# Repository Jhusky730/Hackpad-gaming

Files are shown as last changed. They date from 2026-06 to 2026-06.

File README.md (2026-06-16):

# Hackpad-gaming
This is my hackpad. It consists of a 3x3 key matrix with RGB LEDs, an OLED screen, and a rotary encoder.

Model of hackpad:

54308050-a742-41d1-adb0-8d3222a5e59c

Screenshot of Shematic for PCB:



Screenshot of PCB:



Layers of the keyboard:



Top side of both parts:



The cases act as a clamp and ledge for the pcb to hold it in place:



Bill Of Materials: 
1x Seeed XIAO RP2040  
1x 0.91" OLED9x MX style 1u switches  
9x white blank DSA keycaps  
9x SK6812 Mini-E LEDs  
10x 1N4148 DO-35 Diodes  
1x EC11E Rotary Encoder (With Push Button)  
1x Top case(3D printed)  
1x Middle case(3D printed)  
1x Bottom case(3D printed)  
4x M3x5mx4mm heatset inserts  
4x M3x6mm screws (I will buy these)

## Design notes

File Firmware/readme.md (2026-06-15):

# my_hackpad

my_hackpad

A fully custom 9-key mechanical macropad featuring an orthilinear 3x3 layout, an SSD1306 OLED screen, a rotary encoder, and an addressable per-key SK6812MINI-E RGB matrix. It is pre-configured with a daily desktop utility layer and a dedicated tactical combat deck for EVE Online.

* Keyboard Maintainer: [Jack Huskinson](https://github.com/Jhusky730)
* Hardware Supported: Custom 3x3 PCB, Seeed Studio XIAO RP2040 Controller
* Hardware Availability: Open-source PCB files / Self-sourced components

## Compiling the Firmware

To compile the default layout for this keyboard, run the following command in your QMK CLI environment:

    qmk compile -kb my_hackpad -km default

## Flashing the Microcontroller

Since the Seeed Studio XIAO RP2040 uses a UF2 bootloader, you can flash it using the standard drag-and-drop method:

1. Compile the firmware using the command above to generate the `.uf2` file.
2. Put the keyboard into **Bootloader mode** (see instructions below).
3. A mass storage drive named `RPI-RP2` will appear on your computer.
4. Drag and drop the compiled `my_hackpad_default.uf2` file directly onto that drive. The board will automatically flash and reboot.

See the [build environment setup](https://docs.qmk.fm/#/getting_started_build_tools) and the [make instructions](https://docs.qmk.fm/#/getting_started_make_guide) for more information. Brand new to QMK? Start with our [Complete Newbs Guide](https://docs.qmk.fm/#/newbs).

## Bootloader

Because your board uses a modern RP2040 processor, you can enter the bootloader in 2 reliable hardware ways:

* **Physical Button Combination**: Hold down the **B** (Boot) button on the underside of the XIAO RP2040 module, press and release the **R** (Reset) button, and then release the Boot button.
* **Physical Pads**: If your custom PCB exposes them, briefly short the two `RST` pads together while the device is plugged in.

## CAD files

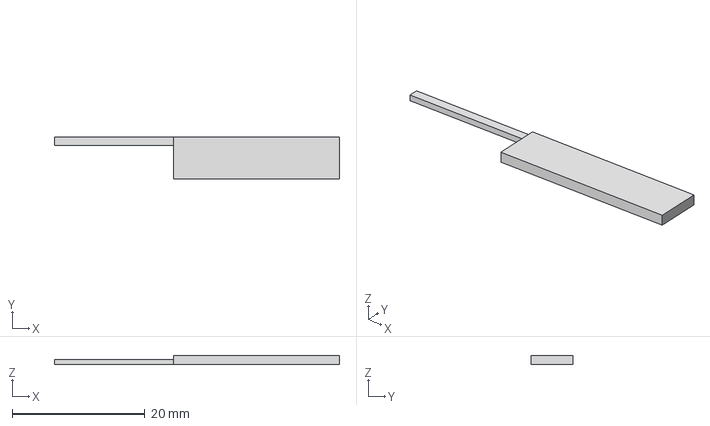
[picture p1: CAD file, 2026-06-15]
Production/Middle.step
43.0 x 6.30 x 1.40 mm

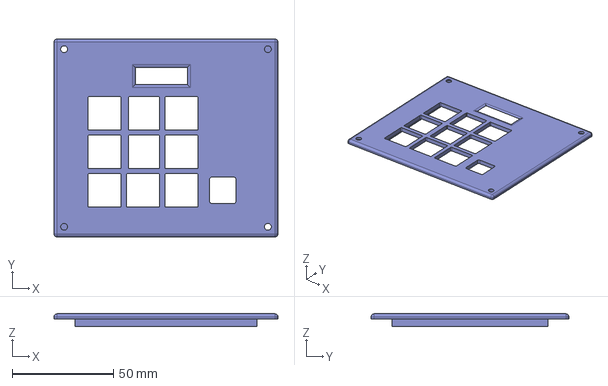
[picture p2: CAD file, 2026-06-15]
Production/Top.step
110.8 x 97.8 x 6.20 mm

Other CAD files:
Production/Bottom.step

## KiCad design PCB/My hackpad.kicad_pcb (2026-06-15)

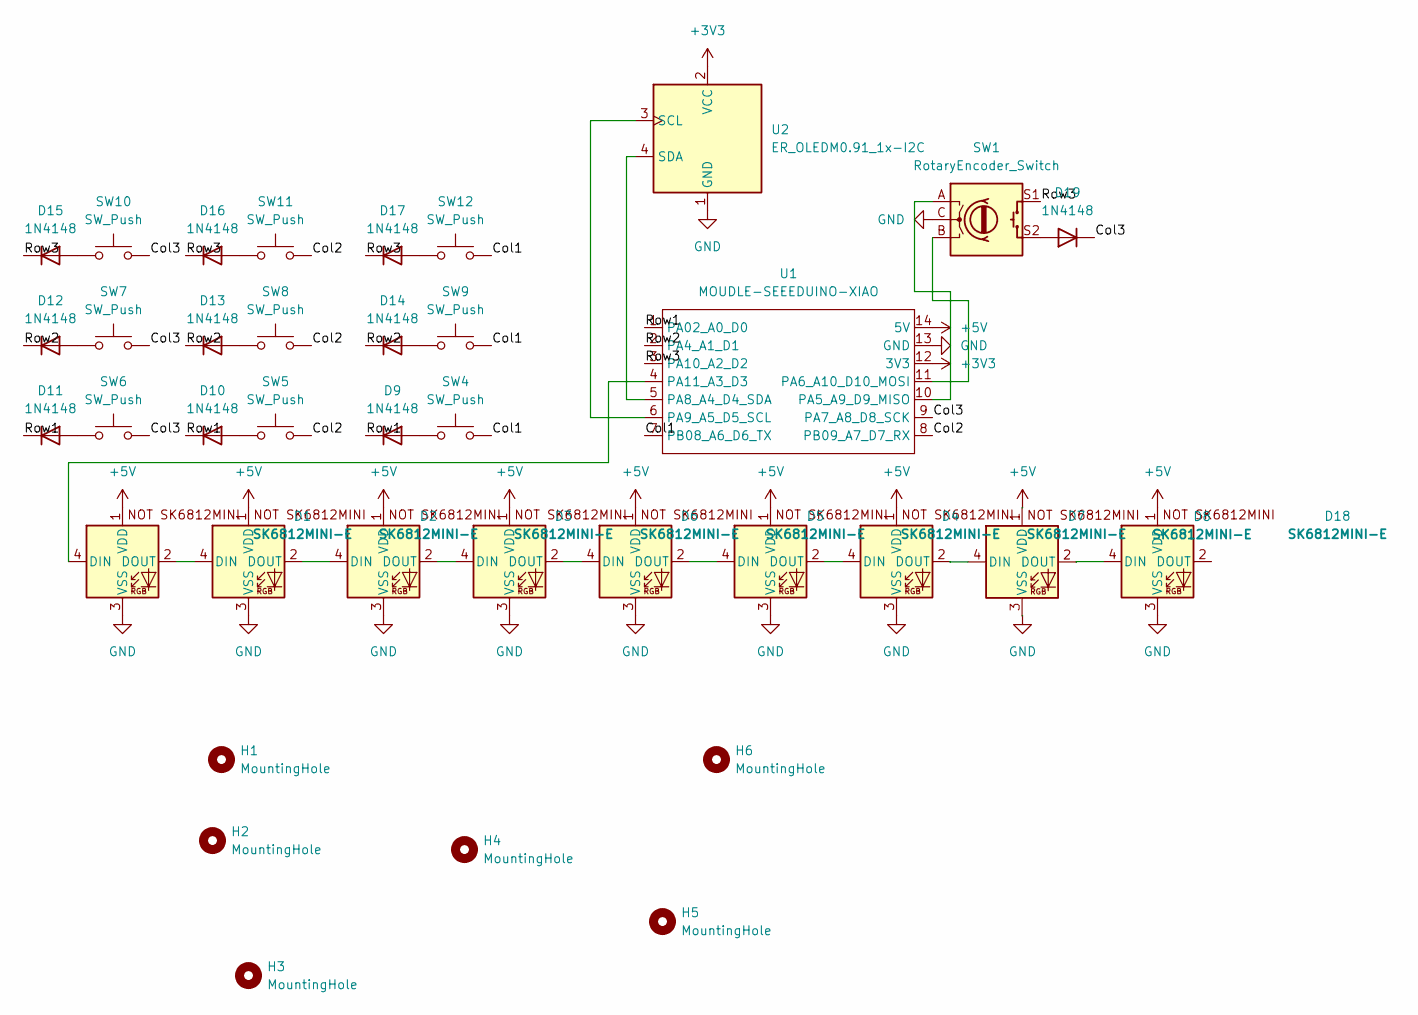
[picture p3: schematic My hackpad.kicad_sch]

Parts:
D1, D2, D3, D4, D5, D6, D7, D8, D18: SK6812MINI-E; SK6812MINI-E_fixed
D9, D10, D11, D12, D13, D14, D15, D16, D17, D19: 1N4148; D_DO-35_SOD27_P7.62mm_Horizontal
H1, H2, H3, H4, H5, H6: MountingHole; MountingHole_3.2mm_M3
SW1: RotaryEncoder_Switch; RotaryEncoder_Alps_EC11E-Switch_Vertical_H20mm_CircularMoun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
SW4, SW5, SW6, SW7, SW8, SW9, SW10, SW11, SW12: SW_Push; SW_Cherry_MX_PCB_1.00u
U1: MOUDLE-SEEEDUINO-XIAO; XIAO-Generic-Hybrid-14P-2.54-21X17.8MM
U2: ER_OLEDM0.91_1x-I2C

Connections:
+3V3: U1.12 (3V3), U2.2 (VCC)
+5V: D1.1 (VDD), D2.1 (VDD), D3.1 (VDD), D4.1 (VDD), D5.1 (VDD), D6.1 (VDD), D7.1 (VDD), D8.1 (VDD), D18.1 (VDD), U1.14 (5V)
/Col1: SW4.2, SW9.2, SW12.2, U1.7 (PB08_A6_D6_TX)
/Col2: SW5.2, SW8.2, SW11.2, U1.8 (PB09_A7_D7_RX)
/Col3: D19.1 (K), SW6.2, SW7.2, SW10.2, U1.9 (PA7_A8_D8_SCK)
/Row1: D9.1 (K), D10.1 (K), D11.1 (K), U1.1 (PA02_A0_D0)
/Row2: D12.1 (K), D13.1 (K), D14.1 (K), U1.2 (PA4_A1_D1)
/Row3: D15.1 (K), D16.1 (K), D17.1 (K), SW1.S1, U1.3 (PA10_A2_D2)
GND: D1.3 (VSS), D2.3 (VSS), D3.3 (VSS), D4.3 (VSS), D5.3 (VSS), D6.3 (VSS), D7.3 (VSS), D8.3 (VSS), D18.3 (VSS), SW1.C, U1.13 (GND), U2.1 (GND)
unnamed: D1.4 (DIN), U1.4 (PA11_A3_D3)
unnamed: D1.2 (DOUT), D2.4 (DIN)
unnamed: D2.2 (DOUT), D3.4 (DIN)
unnamed: D3.2 (DOUT), D6.4 (DIN)
unnamed: D4.4 (DIN), D5.2 (DOUT)
unnamed: D4.2 (DOUT), D7.4 (DIN)
unnamed: D5.4 (DIN), D6.2 (DOUT)
unnamed: D7.2 (DOUT), D8.4 (DIN)
unnamed: D9.2 (A), SW4.1
unnamed: D10.2 (A), SW5.1
unnamed: D11.2 (A), SW6.1
unnamed: D12.2 (A), SW7.1
unnamed: D13.2 (A), SW8.1
unnamed: D14.2 (A), SW9.1
unnamed: D15.2 (A), SW10.1
unnamed: D16.2 (A), SW11.1
unnamed: D17.2 (A), SW12.1
unnamed: D8.2 (DOUT), D18.4 (DIN)
unnamed: D19.2 (A), SW1.S2
unnamed: SW1.A, U1.10 (PA5_A9_D9_MISO)
unnamed: SW1.B, U1.11 (PA6_A10_D10_MOSI)
unnamed: U1.5 (PA8_A4_D4_SDA), U2.4 (SDA)
unnamed: U1.6 (PA9_A5_D5_SCL), U2.3 (SCL)

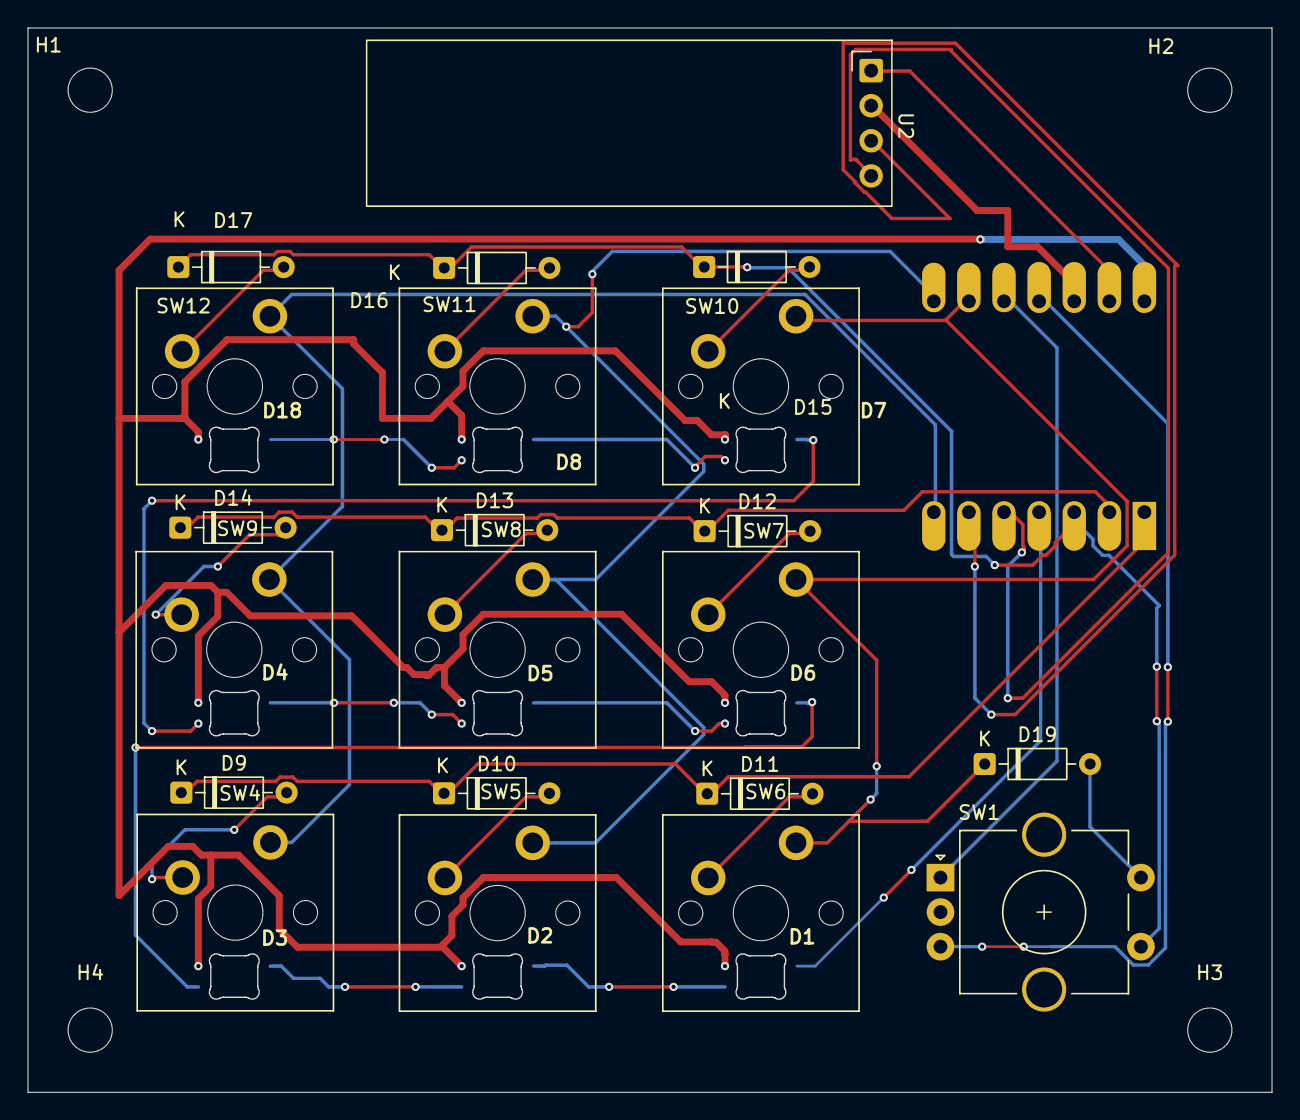
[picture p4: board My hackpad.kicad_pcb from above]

Board: 2 copper layers, 90.0 x 77.0 mm, 35 parts (1 on the bottom side), 32 nets.

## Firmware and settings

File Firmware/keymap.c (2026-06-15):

#include QMK_KEYBOARD_H

// ==========================================
// 1. CUSTOM KEYCODES & VARIABLES
// ==========================================
enum custom_keycodes {
    SHFT_LCK = SAFE_RANGE
};

bool is_shift_locked = false;

// ==========================================
// 2. CUSTOM KEY LOGIC (Shift Lock)
// ==========================================
bool process_record_user(uint16_t keycode, keyrecord_t *record) {
    switch (keycode) {
        case SHFT_LCK:
            if (record->event.pressed) {
                is_shift_locked = !is_shift_locked; 
                
                if (is_shift_locked) {
                    register_code(KC_LSFT);   
                } else {
                    unregister_code(KC_LSFT); 
                }
            }
            return false; 
            
        default:
            return true; 
    }
}

// ==========================================
// 3. LAYOUTS
// ==========================================
const uint16_t PROGMEM keymaps[][MATRIX_ROWS][MATRIX_COLS] = {
    [0] = LAYOUT_ortho_3x3(
        SHFT_LCK, KC_ESC,    TG(1),       // Top Row (Base) - Shift Lock | Escape | Toggle
        RGB_TOG,  RGB_MOD,   RGB_HUI,     // Middle Row (Base): LED Controls
        KC_Z,     KC_X,      KC_C         // Bottom Row (Base): Standard Keys
    ),
    [1] = LAYOUT_ortho_3x3(
        KC_F1,        KC_Q,         TG(1),       // Top Row: F1 | Q | Toggle
        LALT(KC_F2),  LALT(KC_F3),  LALT(KC_F4), // Middle Row: Alt+F2 | Alt+F3 | Alt+F4
        KC_LCTL,      LCTL(KC_F1),  LALT(KC_F1)  // Bottom Row: Ctrl | Ctrl+F1 | Alt+F1
    )
};

// ==========================================
// 4. ROTARY ENCODER
// ==========================================
#if defined(ENCODER_ENABLE) && defined(ENCODER_MAP_ENABLE)
const uint16_t PROGMEM encoder_map[][NUM_ENCODERS][NUM_DIRECTIONS] = {
    // Layer 0 (Base): Left = Open File Explorer | Right = Open Task Manager
    [0] = { ENCODER_CCW_CW(LGUI(KC_E), LCTL(LSFT(KC_ESC))) },
    
    // Layer 1 (EVE): Left = Previous Browser Tab | Right = Next Browser Tab
    [1] = { ENCODER_CCW_CW(LCTL(LSFT(KC_TAB)), LCTL(KC_TAB)) } 
};
#endif

// ==========================================
// 5. OLED SCREEN
// ==========================================
#ifdef OLED_ENABLE
oled_rotation_t oled_init_user(oled_rotation_t rotation) {
    return OLED_ROTATION_0; 
}

bool oled_task_user(void) {
    oled_write_P(PSTR("My Hackpad\n"), false);
    oled_write_P(PSTR("----------\n"), false);
    
    oled_write_P(PSTR("Layer: "), false);
    switch (get_highest_layer(layer_state)) {
        case 0:
            oled_write_P(PSTR("Base \n"), false);
            if (is_shift_locked) {
                oled_write_P(PSTR("[SHIFT LCK ON] \n"), false);
            } else {
                oled_write_P(PSTR("               \n"), false);
            }
            break;
        case 1:
            oled_write_P(PSTR("EVE Online\n"), false); 
            break;
        default:
            oled_write_P(PSTR("Unknown\n"), false);
            break;
    }
    return false;
}
#endif

// ==========================================
// 6. PER-KEY RGB LIGHTING
// ==========================================
#ifdef RGB_MATRIX_ENABLE
bool rgb_matrix_indicators_user(void) {
    switch (get_highest_layer(layer_state)) {
        
        case 0: 
            rgb_matrix_set_color_all(0, 0, 50); 
            
            rgb_matrix_set_color(5, 255, 100, 0); 
            rgb_matrix_set_color(4, 255, 0, 255); 
            rgb_matrix_set_color(3, 0, 255, 255); 
            
            rgb_matrix_set_color(7, 255, 255, 255); 
            
            if (is_shift_locked) {
                rgb_matrix_set_color(8, 255, 0, 0); 
            }
            break;

        case 1: 
            rgb_matrix_set_color_all(0, 0, 0); 
            
            rgb_matrix_set_color(8, 255, 0, 0);
            rgb_matrix_set_color(7, 0, 255, 255);
            
            rgb_matrix_set_color(5, 255, 100, 0);   
            rgb_matrix_set_color(4, 255, 100, 0);   
            rgb_matrix_set_color(3, 255, 100, 0);   
            
            rgb_matrix_set_color(2, 150, 0, 255);   
            rgb_matrix_set_color(1, 150, 0, 255);   
            rgb_matrix_set_color(0, 150, 0, 255);   
            break;
    }
    return false;
}
#endif

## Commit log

2026-06-15 Add Bill of Materials to README
    Added a Bill of Materials section with components list.
2026-06-15 Revise Bill Of Materials formatting in README
    Updated the Bill Of Materials section for clarity and formatting.
2026-06-16 Update README with note on M3x6mm screws purchase
